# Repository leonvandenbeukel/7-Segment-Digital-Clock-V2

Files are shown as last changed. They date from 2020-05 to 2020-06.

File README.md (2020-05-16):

# 7-Segment-Digital-Clock-V2

This is a new version of a 7 segment digital clocks that uses WS2812B LED's. Instructions how to build can be found in the YouTube video.

## License

<br />This work is licensed under a <a rel="license" href="http://creativecommons.org/licenses/by-nc-sa/4.0/">Creative Commons Attribution-NonCommercial-ShareAlike 4.0 International License</a>.

## Components

| Components | x |
| --- | ----- |
|ESP8266 WeMos Mini D1 | 1x |
|DS3231 RTC | 1x |
|Micro USB Breakout board | 1x |
|Micro USB cable | 1x |
|5V 2.5A power supply | 1x |
|WS2812B LED Strip 60 LED's per meter | 2x |

## 3D Printing

Most files can be printed with 0.3 setting and low infill.

## Schema

Connect D6 from the ESP8266 through a 10 ohm resistor to the data pin of the LED strip. Connect the RTC to gnd, vcc and connect SDA and SCLK to the ESP8266 (check the pin layout of the ESP board you are using). Don't power the LED strip from the ESP board but use a Micro USB breakout board en connect the 5V to the LED strip.

## Arduino code

Upload the .ino file to your ESP board. You also need to upload the html and javascript files with the ESP8266FS tool. Check this link for more info:

http://arduino.esp8266.com/Arduino/versions/2.3.0/doc/filesystem.html#uploading-files-to-file-system

Before uploading the files to your ESP board you have to gzip them with the command:

`gzip -r ./data/`

Afterwards if you want to change something to the html files, just unzip with:

`gunzip -r ./data/`

## YouTube video

<a href="https://youtu.be/tGhew6kTAwc" target="_blank">Click to view: 7 Segment Digital Clock V2</a>

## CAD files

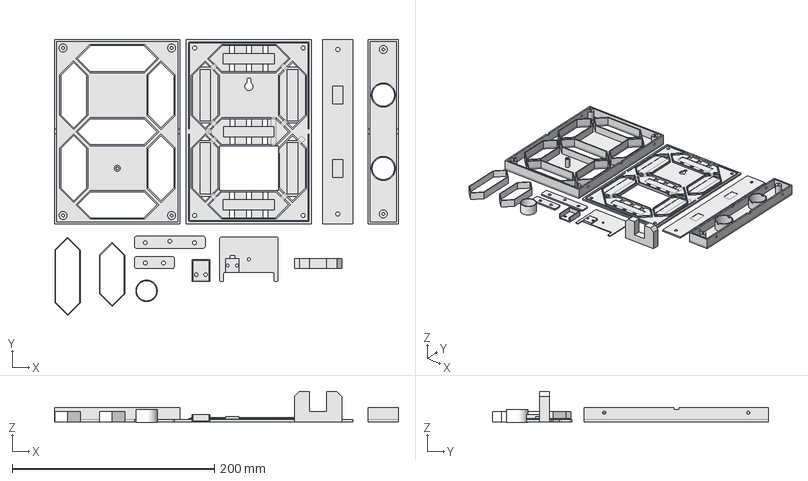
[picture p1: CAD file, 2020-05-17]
Model/3DModel.FCStd
340.0 x 273.0 x 30.8 mm
Bottom
Top
Segment_Vert_Flat
BackLid
MiddleBottom
MiddleTop
Segment_Hor_Flat
Dot
Attach_Large
Attach_Small
USB_Cap
Stand

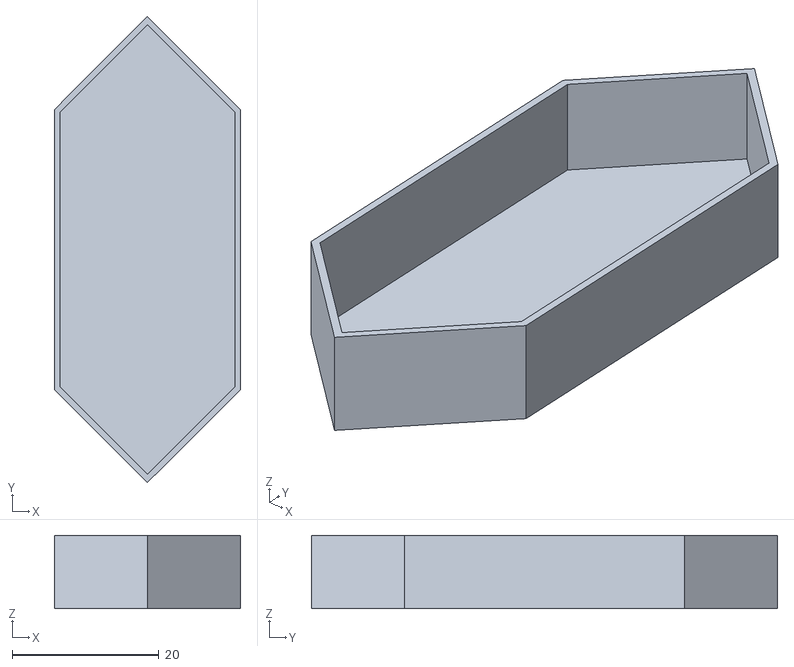
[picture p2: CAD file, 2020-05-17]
STL/Segment_Vert_Flat.stl
25.4 x 63.5 x 10.00

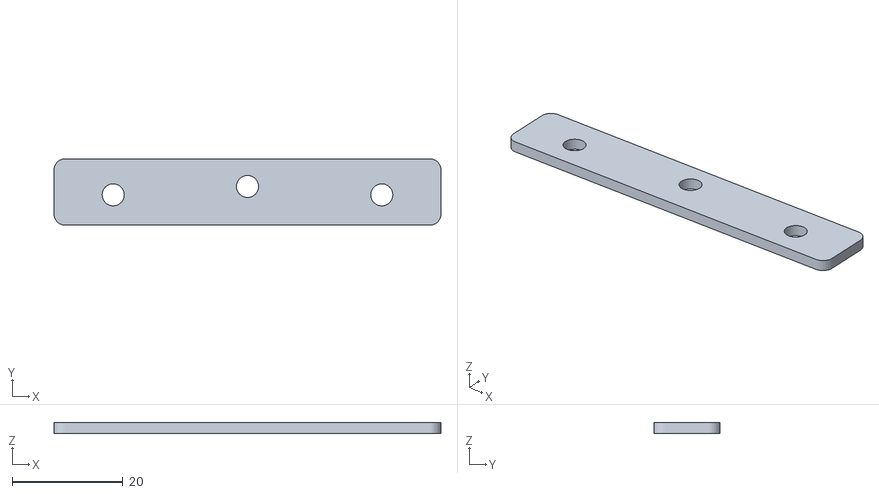
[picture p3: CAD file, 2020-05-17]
STL/Attach_Large.stl
70.0 x 12.0 x 2.00

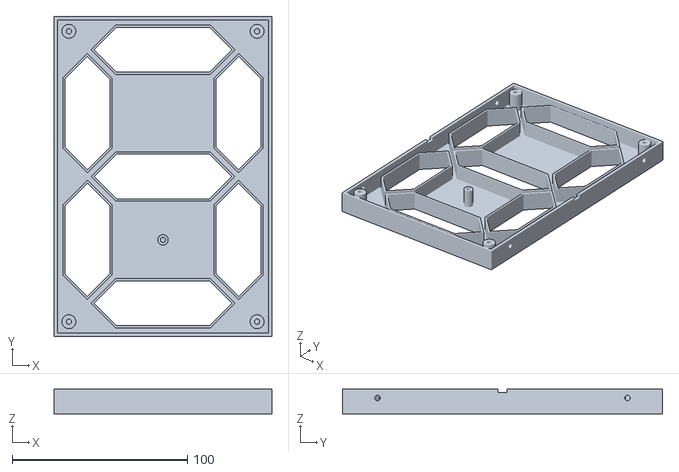
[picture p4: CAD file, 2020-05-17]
STL/Top.stl
124.2 x 182.5 x 14.0

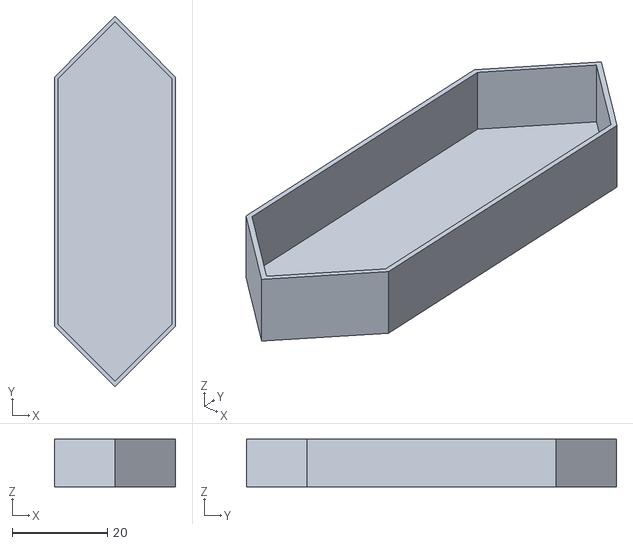
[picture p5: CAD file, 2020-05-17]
STL/Segment_Hor_Flat.stl
25.4 x 77.5 x 10.0

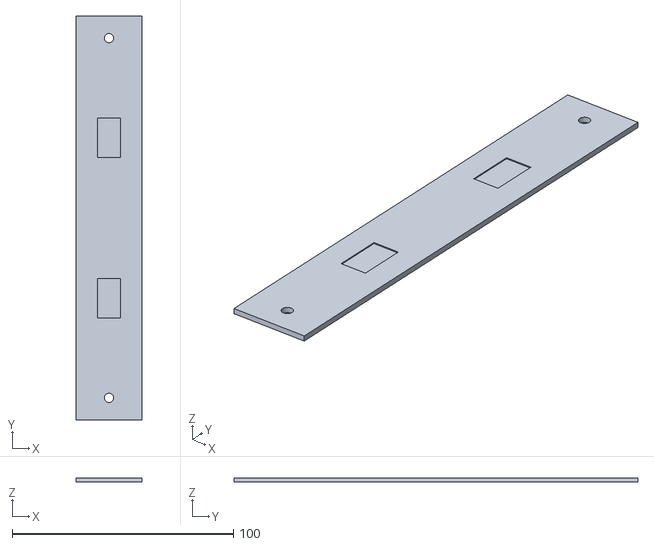
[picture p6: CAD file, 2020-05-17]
STL/MiddleBottom.stl
30.0 x 182.5 x 2.00

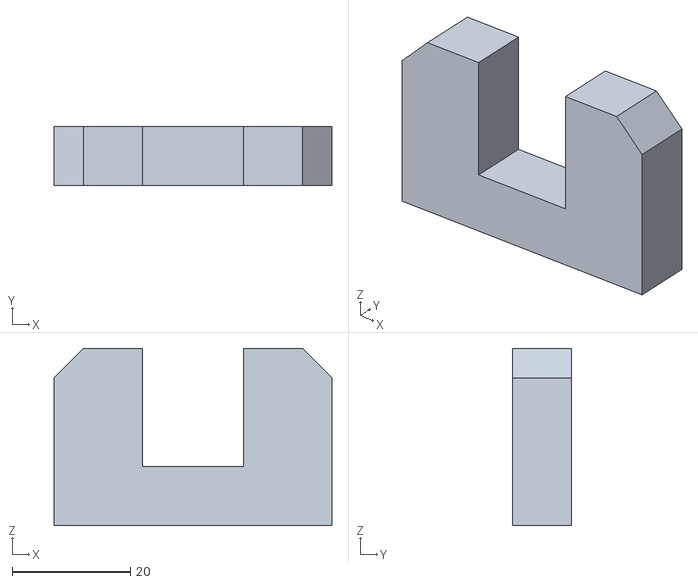
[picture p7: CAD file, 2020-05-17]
STL/Stand.stl
47.0 x 10.0 x 30.0

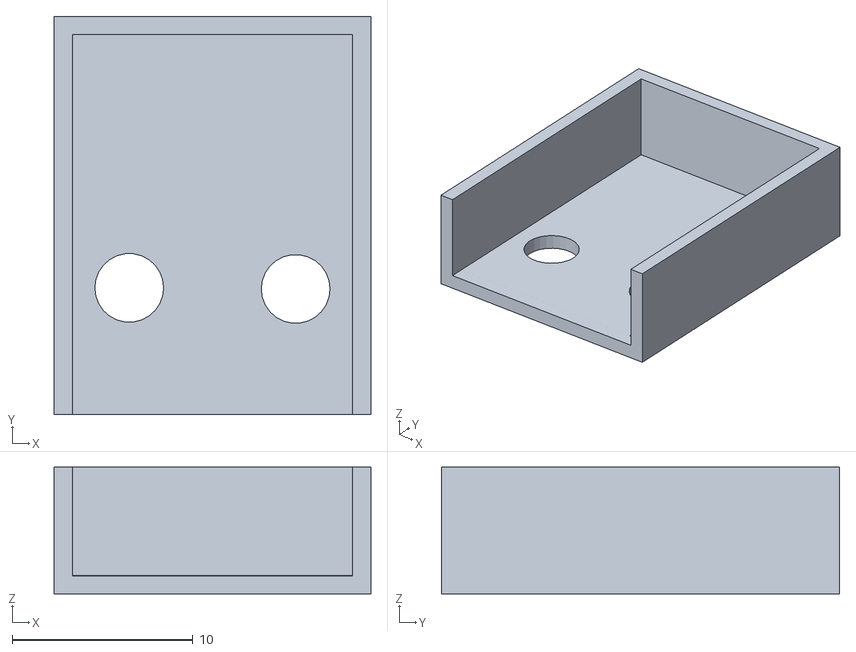
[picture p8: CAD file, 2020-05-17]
STL/USB_Cap.stl
17.5 x 22.0 x 7.00

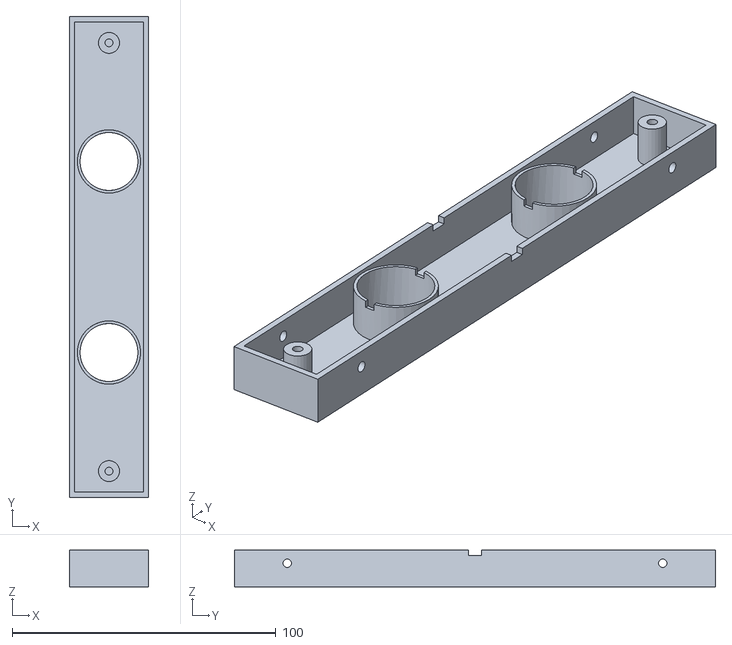
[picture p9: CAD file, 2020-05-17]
STL/MiddleTop.stl
30.0 x 182.5 x 14.0

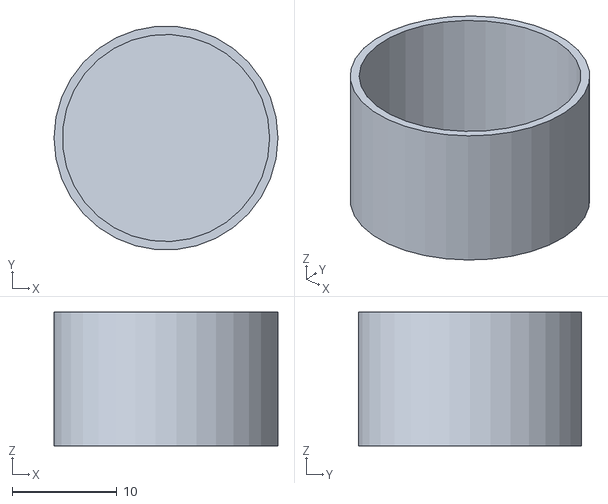
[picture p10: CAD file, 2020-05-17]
STL/Dot.stl
21.4 x 21.3 x 12.8

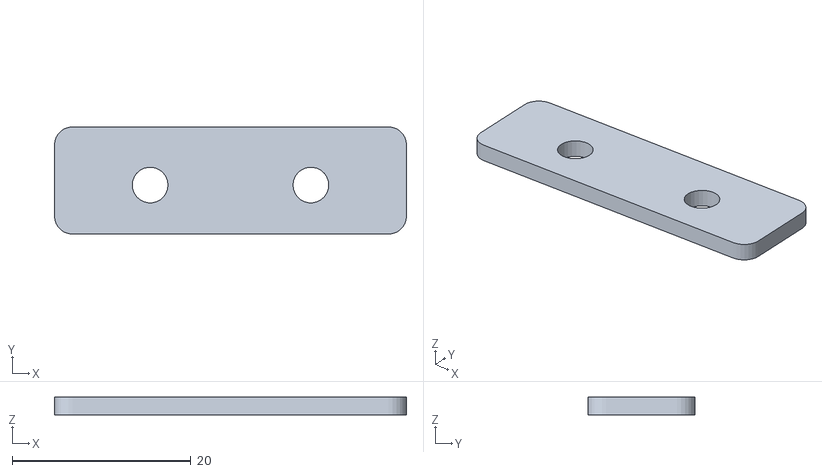
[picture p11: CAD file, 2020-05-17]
STL/Attach_Small.stl
39.4 x 12.0 x 2.00

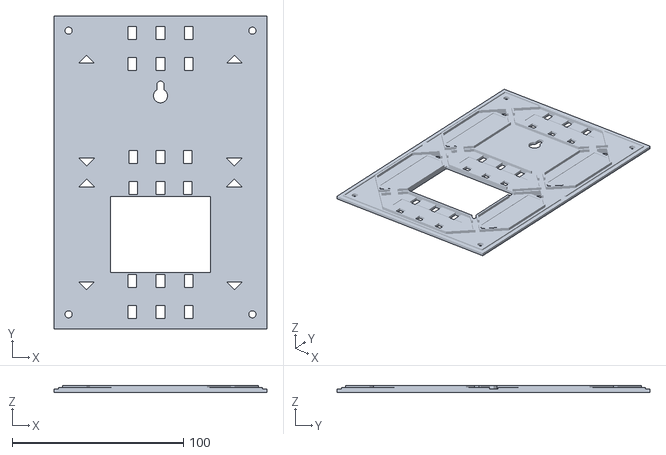
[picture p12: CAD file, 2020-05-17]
STL/Bottom.stl
124.2 x 182.5 x 4.00

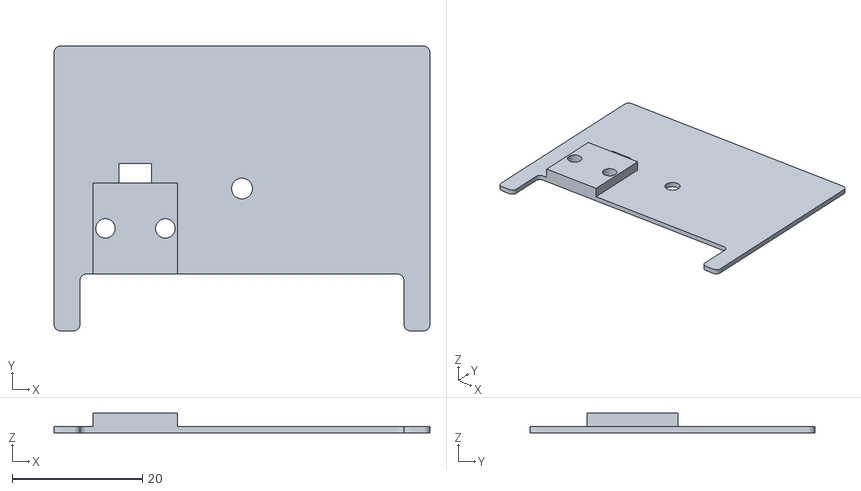
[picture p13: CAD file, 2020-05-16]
STL/Backlid.stl
57.7 x 43.7 x 3.00

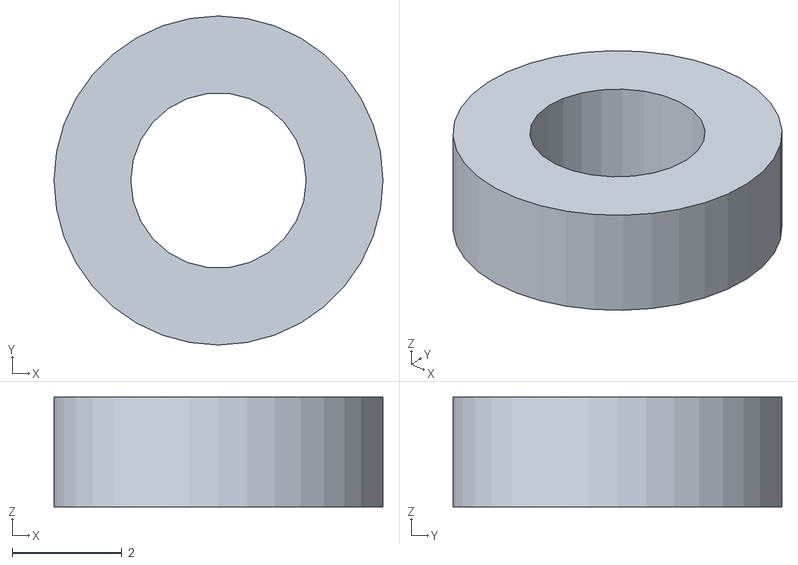
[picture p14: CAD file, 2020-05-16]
STL/Spacer.stl
6.00 x 6.00 x 2.00

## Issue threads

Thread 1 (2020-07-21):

RTC Pin on ESP8266

GreenRisc, 2020-07-21:
Hi everyone,

the RTC module has a few Pins and i don´t know, which Pins i have to connect on which pins on the esp8266.
My second problem is, the clock is blinking red. Why?

best wishes

yusufsulaiman, 2021-02-24:
scl D1
SDA D2

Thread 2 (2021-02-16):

Add 5 LED / Strip - 7 Segment Digital Clock

Eka1911, 2021-02-16:
Dear Leon,

I tried to make it by increasing the number of LEDs / Strips, from 3 LEDs to 5 LEDs.

But when you turn it on, many of the leds don't light up.
The following sketch that I changed.

Please provide solutions and directions, so that it can be perfect.

Thank you.

#include <Wire.h>
#include <RtcDS3231.h>                        // Include RTC library by Makuna: https://github.com/Makuna/Rtc
#include <ESP8266WiFi.h>
#include <ESP8266WebServer.h>
#include <ESP8266HTTPUpdateServer.h>
#include <FastLED.h>
#include <FS.h>                               // Please read the instructions on http://arduino.esp8266.com/Arduino/versions/2.3.0/doc/filesystem.html#uploading-files-to-file-system
#define countof(a) (sizeof(a) / sizeof(a[0]))
#define NUM_LEDS 142                           // Total of 142 LED's    ////5 led per segment X 7 segment X 4 digit + 2 dot titik
#define DATA_PIN D6                           // Change this if you are using another type of ESP board than a WeMos D1 Mini
#define MILLI_AMPS 4000                        // asumsi 800mA jika 1ed per segment maka 5 ledper segment 4.000mA
#define COUNTDOWN_OUTPUT D5                    // COUNTDOWN_OUTPUT D5 to buzzer 3 beeps when the countdown timer is reached

#define WIFIMODE 2                            // 0 = Only Soft Access Point, 1 = Only connect to local WiFi network with UN/PW, 2 = Both

#if defined(WIFIMODE) && (WIFIMODE == 0 || WIFIMODE == 2)
  const char* APssid = "7Segment-5Led";
  const char* APpassword = "1234567890";
#endif

#if defined(WIFIMODE) && (WIFIMODE == 1 || WIFIMODE == 2)
  #include "Credentials.h"                    // Create this file in the same directory as the .ino file and add your credentials (#define SID YOURSSID and on the second line #define PW YOURPASSWORD)
  const char *ssid = SID;
  const char *password = PW;
#endif

RtcDS3231<TwoWire> Rtc(Wire);
ESP8266WebServer server(80);
ESP8266HTTPUpdateServer httpUpdateServer;
CRGB LEDs[NUM_LEDS];

// Settings
unsigned long prevTime = 0;
byte r_val = 255;
byte g_val = 0;
byte b_val = 0;
bool dotsOn = true;
byte brightness = 255;
float temperatureCorrection = -3.0;
byte temperatureSymbol = 12;                  // 12=Celcius, 13=Fahrenheit check 'numbers'
byte clockMode = 0;                           // Clock modes: 0=Clock, 1=Countdown, 2=Temperature, 3=Scoreboard
unsigned long countdownMilliSeconds;
unsigned long endCountDownMillis;
byte hourFormat = 24;                         // Change this to 12 if you want default 12 hours format instead of 24       
CRGB countdownColor = CRGB::Green;
byte scoreboardLeft = 0;
byte scoreboardRight = 0;
CRGB scoreboardColorLeft = CRGB::Green;
CRGB scoreboardColorRight = CRGB::Red;
CRGB alternateColor = CRGB::Black;
long numbers[] = {
  0b00000111111111111111111111111111111,  // [0] 0                  ////5 led per segment
  0b00000111110000000000000000000011111,  // [1] 1                  ////5 led per segment
  0b11111111111111100000111111111100000,  // [2] 2                  ////5 led per segment
  0b11111111111111100000000001111111111,  // [3] 3                  ////5 led per segment
  0b11111111110000011111000000000011111,  // [4] 4                  ////5 led per segment
  0b11111000001111111111000001111111111,  // [5] 5                  ////5 led per segment
  0b11111000001111111111111111111111111,  // [6] 6                  ////5 led per segment
  0b00000111111111100000000000000011111,  // [7] 7                  ////5 led per segment
  0b11111111111111111111111111111111111,  // [8] 8                  ////5 led per segment
  0b11111111111111111111000001111111111,  // [9] 9                  ////5 led per segment
  0b00000000000000000000000000000000000,  // [10] off               ////5 led per segment
  0b11111111111111111111000000000000000,  // [11] degrees symbol    ////5 led per segment
  0b00000000001111111111111111111100000,  // [12] C(elsius)         ////5 led per segment
  0b11111000001111111111111110000000000,  // [13] F(ahrenheit)      ////5 led per segment
};

void setup() {
  pinMode(COUNTDOWN_OUTPUT, OUTPUT);
  Serial.begin(115200);
  delay(200);

  // RTC DS3231 Setup
  Rtc.Begin();
  RtcDateTime compiled = RtcDateTime(__DATE__, __TIME__);

  if (!Rtc.IsDateTimeValid()) {
      if (Rtc.LastError() != 0) {
          // we have a communications error see https://www.arduino.cc/en/Reference/WireEndTransmission for what the number means
          Serial.print("RTC communications error = ");
          Serial.println(Rtc.LastError());
      } else {
          // Common Causes:
          //    1) first time you ran and the device wasn't running yet
          //    2) the battery on the device is low or even missing
          Serial.println("RTC lost confidence in the DateTime!");
          // following line sets the RTC to the date & time this sketch was compiled
          // it will also reset the valid flag internally unless the Rtc device is
          // having an issue
          Rtc.SetDateTime(compiled);
      }
  }

  WiFi.setSleepMode(WIFI_NONE_SLEEP);

  delay(200);
  //Serial.setDebugOutput(true);

  FastLED.addLeds<WS2812B, DATA_PIN, GRB>(LEDs, NUM_LEDS);
  FastLED.setDither(false);
  FastLED.setCorrection(TypicalLEDStrip);
  FastLED.setMaxPowerInVoltsAndMilliamps(5, MILLI_AMPS);
  fill_solid(LEDs, NUM_LEDS, CRGB::Black);
  FastLED.show();

  // WiFi - AP Mode or both
#if defined(WIFIMODE) && (WIFIMODE == 0 || WIFIMODE == 2)
  WiFi.mode(WIFI_AP_STA);
  WiFi.softAP(APssid, APpassword);    // IP is usually 192.168.4.1
  Serial.println();
  Serial.print("SoftAP IP: ");
  Serial.println(WiFi.softAPIP());
#endif

  // WiFi - Local network Mode or both
#if defined(WIFIMODE) && (WIFIMODE == 1 || WIFIMODE == 2)
  byte count = 0;
  WiFi.begin(ssid, password);
  while (WiFi.status() != WL_CONNECTED) {
    // Stop if cannot connect
    if (count >= 60) {
      Serial.println("Could not connect to local WiFi.");
      return;
    }

    delay(500);
    Serial.print(".");
    LEDs[count] = CRGB::Green;
    FastLED.show();
    count++;
  }
  Serial.print("Local IP: ");
  Serial.println(WiFi.localIP());

  IPAddress ip = WiFi.localIP();
  Serial.println(ip[3]);
#endif

  httpUpdateServer.setup(&server);

  // Handlers
  server.on("/color", HTTP_POST, []() {
    r_val = server.arg("r").toInt();
    g_val = server.arg("g").toInt();
    b_val = server.arg("b").toInt();
    server.send(200, "text/json", "{\"result\":\"ok\"}");
  });

  server.on("/setdate", HTTP_POST, []() {
    // Sample input: date = "Dec 06 2009", time = "12:34:56"
    // Jan Feb Mar Apr May Jun Jul Aug Sep Oct Nov Dec
    String datearg = server.arg("date");
    String timearg = server.arg("time");
    Serial.println(datearg);
    Serial.println(timearg);
    char d[12];
    char t[9];
    datearg.toCharArray(d, 12);
    timearg.toCharArray(t, 9);
    RtcDateTime compiled = RtcDateTime(d, t);
    Rtc.SetDateTime(compiled);
    clockMode = 0;
    server.send(200, "text/json", "{\"result\":\"ok\"}");
  });

  server.on("/brightness", HTTP_POST, []() {
    brightness = server.arg("brightness").toInt();
    server.send(200, "text/json", "{\"result\":\"ok\"}");
  });

  server.on("/countdown", HTTP_POST, []() {
    countdownMilliSeconds = server.arg("ms").toInt();
    byte cd_r_val = server.arg("r").toInt();
    byte cd_g_val = server.arg("g").toInt();
    byte cd_b_val = server.arg("b").toInt();
    digitalWrite(COUNTDOWN_OUTPUT, LOW);
    countdownColor = CRGB(cd_r_val, cd_g_val, cd_b_val);
    endCountDownMillis = millis() + countdownMilliSeconds;
    allBlank();
    clockMode = 1;
    server.send(200, "text/json", "{\"result\":\"ok\"}");
  });
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
niall-cooley, 2021-04-08:
Hi @MacGyverr im not 100% sure I would need to try it… You could possibly use a float?

helpquick, 2021-04-08:
@MacGyverr @niall-cooley
You can't use float or double as the numbers array essentially holds a bitmap of which LEDs should be lit or not for each digit.

Why will ``long long`` not work? it should be 64 bits, which is enough to hold the required 49-bit bitmap? (I haven't actually tried more than 3 LEDs per segment).

niall-cooley, 2021-04-08:
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

@helpquick  your completely right I didn’t think on it like that! Just an update with help from your comments above I got 2 per segment working perfectly 😊
![Uploading 0206B1BD-874F-4C83-B346-B5FC2F80FC94.jpeg…]()

MacGyverr, 2021-04-08:
It starts to do weird things above 32 per segment, like never turning off certain lights and turning on less than the number it should, and if I use long long, the 32nd or 33rd light stays out all down the strip and it doesn't work right.
This array method looks promising:
byte digits[12][28] = {{0,0,0,0,1,1,1,1,1,1,1,1,1,1,1,1,1,1,1,1,1,1,1,1,1,1,1,1},   // Digit 0
                       {0,0,0,0,1,1,1,1,0,0,0,0,0,0,0,0,0,0,0,0,0,0,0,0,1,1,1,1},   // Digit 1
                       {1,1,1,1,1,1,1,1,1,1,1,1,0,0,0,0,1,1,1,1,1,1,1,1,0,0,0,0},   // Digit 2
                       {1,1,1,1,1,1,1,1,1,1,1,1,0,0,0,0,0,0,0,0,1,1,1,1,1,1,1,1},   // Digit 3
                       {1,1,1,1,1,1,1,1,0,0,0,0,1,1,1,1,0,0,0,0,0,0,0,0,1,1,1,1},   // Digit 4
                       {1,1,1,1,0,0,0,0,1,1,1,1,1,1,1,1,0,0,0,0,1,1,1,1,1,1,1,1},   // Digit 5
                       {1,1,1,1,0,0,0,0,1,1,1,1,1,1,1,1,1,1,1,1,1,1,1,1,1,1,1,1},   // Digit 6
                       {0,0,0,0,1,1,1,1,1,1,1,1,0,0,0,0,0,0,0,0,0,0,0,0,1,1,1,1},   // Digit 7
                       {1,1,1,1,1,1,1,1,1,1,1,1,1,1,1,1,1,1,1,1,1,1,1,1,1,1,1,1},   // Digit 8
                       {1,1,1,1,1,1,1,1,1,1,1,1,1,1,1,1,0,0,0,0,1,1,1,1,1,1,1,1},   // Digit 9 | 2D Array for numbers on 7 segment
                       {1,1,1,1,1,1,1,1,1,1,1,1,1,1,1,1,0,0,0,0,0,0,0,0,0,0,0,0},   // Digit *0
                       {0,0,0,0,0,0,0,0,1,1,1,1,1,1,1,1,1,1,1,1,1,1,1,1,0,0,0,0}};  // Digit C
and then
      for(int k=0; k<=27;k++){
        // Serial.print(digits[digit][k]);
        if (digits[digit][k]== 1){leds[cursor]=ledColor;}
         else if (digits[digit][k]==0){leds[cursor]=0x000000;};
         cursor ++;
        };
But my complete lack of programming skills and my inability to fix a simple size issue, makes me think I'll never be able to convert Leon's superior web-server based code into using that either. :)

helpquick, 2021-04-08:
Alternative option would be to have the numbers[] array be just 1 bit per segment, then add an extra for loop to expand it to the number of LEDs

```
// bitmap for LEDs
byte numbers[] = {
//  7654321
  0b0111111,  // [0] 0
  0b0100001,  // [1] 1
  0b1110110,  // [2] 2
  0b1110011,  // [3] 3
  0b1101001,  // [4] 4
  0b1011011,  // [5] 5
  0b1011111,  // [6] 6
  0b0110001,  // [7] 7
  0b1111111,  // [8] 8
  0b1111011,  // [9] 9
  0b0000000,  // [10] off
  0b1111000,  // [11] degrees symbol
  0b0011110,  // [12] C(elsius)
  0b1011100,  // [13] F(ahrenheit)
};
```

then:
 in the `displayNumber` function:

```
  for (byte i=0; i<7; i++){                // 7 segments
    for (byte j=0; j<7; j++ {              // 7 LEDs per segment
      yield();
      LEDs[j + i + startindex] = ((numbers[number] & 1 << i) == 1 << i) ? color : alternateColor;
    }
  }
```

This is just an idea, I've not tested it.

MacGyverr, 2021-04-09:
That worked perfectly, I don't know why I didn't think to do that in the first place, it is so simple but so clever and best I can tell, doesn't cause any extra flickering or anything.
Thank you so much, you saved me soooooo much unnecessary work. :)

helpquick, 2021-04-16:
In case anyone is interested, I have uploaded an improved version of the code here: [7-Segment-WiFi-Clock](https://github.com/helpquick/7-Segment-WiFi-Clock)

I am still working on improvements, but as it stands, number of LEDs per segment can be configured, WiFi uses AutoConnect captive portal, so no need for hard-coded SSID / PSK, and time will update from NTP.

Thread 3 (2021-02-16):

Add 5 LED / Strip - 7 Segment Digital Clock

Eka1911, 2021-02-16:
Dear Leon,

I tried to make it by increasing the number of LEDs / Strips, from 3 LEDs to 5 LEDs.

But when you turn it on, many of the leds don't light up.
The following sketch that I changed.

Please provide solutions and directions, so that it can be perfect.

Thank you.

#include <Wire.h>
#include <RtcDS3231.h>                        // Include RTC library by Makuna: https://github.com/Makuna/Rtc
#include <ESP8266WiFi.h>
#include <ESP8266WebServer.h>
#include <ESP8266HTTPUpdateServer.h>
#include <FastLED.h>
#include <FS.h>                               // Please read the instructions on http://arduino.esp8266.com/Arduino/versions/2.3.0/doc/filesystem.html#uploading-files-to-file-system
#define countof(a) (sizeof(a) / sizeof(a[0]))
#define NUM_LEDS 142                           // Total of 142 LED's    ////5 led per segment X 7 segment X 4 digit + 2 dot titik
#define DATA_PIN D6                           // Change this if you are using another type of ESP board than a WeMos D1 Mini
#define MILLI_AMPS 4000                        // asumsi 800mA jika 1ed per segment maka 5 ledper segment 4.000mA
#define COUNTDOWN_OUTPUT D5                    // COUNTDOWN_OUTPUT D5 to buzzer 3 beeps when the countdown timer is reached

#define WIFIMODE 2                            // 0 = Only Soft Access Point, 1 = Only connect to local WiFi network with UN/PW, 2 = Both

#if defined(WIFIMODE) && (WIFIMODE == 0 || WIFIMODE == 2)
  const char* APssid = "7Segment-5Led";
  const char* APpassword = "1234567890";
#endif

#if defined(WIFIMODE) && (WIFIMODE == 1 || WIFIMODE == 2)
  #include "Credentials.h"                    // Create this file in the same directory as the .ino file and add your credentials (#define SID YOURSSID and on the second line #define PW YOURPASSWORD)
  const char *ssid = SID;
  const char *password = PW;
#endif

RtcDS3231<TwoWire> Rtc(Wire);
ESP8266WebServer server(80);
ESP8266HTTPUpdateServer httpUpdateServer;
CRGB LEDs[NUM_LEDS];

// Settings
unsigned long prevTime = 0;
byte r_val = 255;
byte g_val = 0;
byte b_val = 0;
bool dotsOn = true;
byte brightness = 255;
float temperatureCorrection = -3.0;
byte temperatureSymbol = 12;                  // 12=Celcius, 13=Fahrenheit check 'numbers'
byte clockMode = 0;                           // Clock modes: 0=Clock, 1=Countdown, 2=Temperature, 3=Scoreboard
unsigned long countdownMilliSeconds;
unsigned long endCountDownMillis;
byte hourFormat = 24;                         // Change this to 12 if you want default 12 hours format instead of 24       
CRGB countdownColor = CRGB::Green;
byte scoreboardLeft = 0;
byte scoreboardRight = 0;
CRGB scoreboardColorLeft = CRGB::Green;
CRGB scoreboardColorRight = CRGB::Red;
CRGB alternateColor = CRGB::Black;
long numbers[] = {
  0b00000111111111111111111111111111111,  // [0] 0                  ////5 led per segment
  0b00000111110000000000000000000011111,  // [1] 1                  ////5 led per segment
  0b11111111111111100000111111111100000,  // [2] 2                  ////5 led per segment
  0b11111111111111100000000001111111111,  // [3] 3                  ////5 led per segment
  0b11111111110000011111000000000011111,  // [4] 4                  ////5 led per segment
  0b11111000001111111111000001111111111,  // [5] 5                  ////5 led per segment
  0b11111000001111111111111111111111111,  // [6] 6                  ////5 led per segment
  0b00000111111111100000000000000011111,  // [7] 7                  ////5 led per segment
  0b11111111111111111111111111111111111,  // [8] 8                  ////5 led per segment
  0b11111111111111111111000001111111111,  // [9] 9                  ////5 led per segment
  0b00000000000000000000000000000000000,  // [10] off               ////5 led per segment
  0b11111111111111111111000000000000000,  // [11] degrees symbol    ////5 led per segment
  0b00000000001111111111111111111100000,  // [12] C(elsius)         ////5 led per segment
  0b11111000001111111111111110000000000,  // [13] F(ahrenheit)      ////5 led per segment
};

void setup() {
  pinMode(COUNTDOWN_OUTPUT, OUTPUT);
  Serial.begin(115200);
  delay(200);

  // RTC DS3231 Setup
  Rtc.Begin();
  RtcDateTime compiled = RtcDateTime(__DATE__, __TIME__);

  if (!Rtc.IsDateTimeValid()) {
      if (Rtc.LastError() != 0) {
          // we have a communications error see https://www.arduino.cc/en/Reference/WireEndTransmission for what the number means
          Serial.print("RTC communications error = ");
          Serial.println(Rtc.LastError());
      } else {
          // Common Causes:
          //    1) first time you ran and the device wasn't running yet
          //    2) the battery on the device is low or even missing
          Serial.println("RTC lost confidence in the DateTime!");
          // following line sets the RTC to the date & time this sketch was compiled
          // it will also reset the valid flag internally unless the Rtc device is
          // having an issue
          Rtc.SetDateTime(compiled);
      }
  }

  WiFi.setSleepMode(WIFI_NONE_SLEEP);

  delay(200);
  //Serial.setDebugOutput(true);

  FastLED.addLeds<WS2812B, DATA_PIN, GRB>(LEDs, NUM_LEDS);
  FastLED.setDither(false);
  FastLED.setCorrection(TypicalLEDStrip);
  FastLED.setMaxPowerInVoltsAndMilliamps(5, MILLI_AMPS);
  fill_solid(LEDs, NUM_LEDS, CRGB::Black);
  FastLED.show();

  // WiFi - AP Mode or both
#if defined(WIFIMODE) && (WIFIMODE == 0 || WIFIMODE == 2)
  WiFi.mode(WIFI_AP_STA);
  WiFi.softAP(APssid, APpassword);    // IP is usually 192.168.4.1
  Serial.println();
  Serial.print("SoftAP IP: ");
  Serial.println(WiFi.softAPIP());
#endif

  // WiFi - Local network Mode or both
#if defined(WIFIMODE) && (WIFIMODE == 1 || WIFIMODE == 2)
  byte count = 0;
  WiFi.begin(ssid, password);
  while (WiFi.status() != WL_CONNECTED) {
    // Stop if cannot connect
    if (count >= 60) {
      Serial.println("Could not connect to local WiFi.");
      return;
    }

    delay(500);
    Serial.print(".");
    LEDs[count] = CRGB::Green;
    FastLED.show();
    count++;
  }
  Serial.print("Local IP: ");
  Serial.println(WiFi.localIP());

  IPAddress ip = WiFi.localIP();
  Serial.println(ip[3]);
#endif

  httpUpdateServer.setup(&server);

  // Handlers
  server.on("/color", HTTP_POST, []() {
    r_val = server.arg("r").toInt();
    g_val = server.arg("g").toInt();
    b_val = server.arg("b").toInt();
    server.send(200, "text/json", "{\"result\":\"ok\"}");
  });

  server.on("/setdate", HTTP_POST, []() {
    // Sample input: date = "Dec 06 2009", time = "12:34:56"
    // Jan Feb Mar Apr May Jun Jul Aug Sep Oct Nov Dec
    String datearg = server.arg("date");
    String timearg = server.arg("time");
    Serial.println(datearg);
    Serial.println(timearg);
    char d[12];
    char t[9];
    datearg.toCharArray(d, 12);
    timearg.toCharArray(t, 9);
    RtcDateTime compiled = RtcDateTime(d, t);
    Rtc.SetDateTime(compiled);
    clockMode = 0;
    server.send(200, "text/json", "{\"result\":\"ok\"}");
  });

  server.on("/brightness", HTTP_POST, []() {
    brightness = server.arg("brightness").toInt();
    server.send(200, "text/json", "{\"result\":\"ok\"}");
  });

  server.on("/countdown", HTTP_POST, []() {
    countdownMilliSeconds = server.arg("ms").toInt();
    byte cd_r_val = server.arg("r").toInt();
    byte cd_g_val = server.arg("g").toInt();
    byte cd_b_val = server.arg("b").toInt();
    digitalWrite(COUNTDOWN_OUTPUT, LOW);
    countdownColor = CRGB(cd_r_val, cd_g_val, cd_b_val);
    endCountDownMillis = millis() + countdownMilliSeconds;
    allBlank();
    clockMode = 1;
    server.send(200, "text/json", "{\"result\":\"ok\"}");
  });

  server.on("/temperature", HTTP_POST, []() {
    temperatureCorrection = server.arg("correction").toInt();
    temperatureSymbol = server.arg("symbol").toInt();
    clockMode = 2;
    server.send(200, "text/json", "{\"result\":\"ok\"}");
  });

  server.on("/scoreboard", HTTP_POST, []() {
    scoreboardLeft = server.arg("left").toInt();
    scoreboardRight = server.arg("right").toInt();
    scoreboardColorLeft = CRGB(server.arg("rl").toInt(),server.arg("gl").toInt(),server.arg("bl").toInt());
    scoreboardColorRight = CRGB(server.arg("rr").toInt(),server.arg("gr").toInt(),server.arg("br").toInt());
    clockMode = 3;
    server.send(200, "text/json", "{\"result\":\"ok\"}");
  });

  server.on("/hourformat", HTTP_POST, []() {
    hourFormat = server.arg("hourformat").toInt();
    clockMode = 0;
    server.send(200, "text/json", "{\"result\":\"ok\"}");
  });

  server.on("/clock", HTTP_POST, []() {
    clockMode = 0;
    server.send(200, "text/json", "{\"result\":\"ok\"}");
  });

  // Before uploading the files with the "ESP8266 Sketch Data Upload" tool, zip the files with the command "gzip -r ./data/" (on Windows I do this with a Git Bash)
  // *.gz files are automatically unpacked and served from your ESP (so you don't need to create a handler for each file).
  server.serveStatic("/", SPIFFS, "/", "max-age=86400");
  server.begin();

  SPIFFS.begin();
  Serial.println("SPIFFS contents:");
  Dir dir = SPIFFS.openDir("/");
  while (dir.next()) {
    String fileName = dir.fileName();
    size_t fileSize = dir.fileSize();
    Serial.printf("FS File: %s, size: %s\n", fileName.c_str(), String(fileSize).c_str());
  }
  Serial.println();

  digitalWrite(COUNTDOWN_OUTPUT, LOW);
}

void loop(){

  server.handleClient();

  unsigned long currentMillis = millis();
  if (currentMillis - prevTime >= 1000) {
    prevTime = currentMillis;

    if (clockMode == 0) {
      updateClock();
    } else if (clockMode == 1) {
      updateCountdown();
    } else if (clockMode == 2) {
      updateTemperature();
    } else if (clockMode == 3) {
      updateScoreboard();    
    }

    FastLED.setBrightness(brightness);
    FastLED.show();
  }
}

void displayNumber(byte number, byte segment, CRGB color) {
  /*
   *
      __ __ __        __ __ __          __ __ __        12 13 14
    __        __    __        __      __        __    11        15
    __        __    __        __      __        __    10        16
    __        __    __        __ /71  __        __    _9        17
     141 __ __        __ __ __          __ __ __        34 19 18             //////////KETERANGAN BISA DILIHAT DI KONFIGURASI LED 5 PIXEL.JPG           
    __      /107   __        /72 /70  __       /35   _8        _/0
    __        __    __        __      __        __    _7        _1
    __        __    __        __      __        __    _6        _2
      __ __ __       __ __ __           __ __ __       _5 _4 _3

   */

  // segment from left to right: 3, 2, 1, 0
  byte startindex = 0;
  switch (segment) {
    case 0:
      startindex = 0;         //// value start index digit 1 led no 0.
      break;
    case 1:
      startindex = 35;        //// value start index digit 2 led no 35.
      break;
    case 2:
      startindex = 72;        //// value start index digit 3 led no 72.
      break;
    case 3:
      startindex = 107;        //// value start index digit 4 led no 107.
      break;
  }

  for (byte i=0; i<35; i++){   //// value start index digit 2 led no 35.
    yield();
    LEDs[i + startindex] = ((numbers[number] & 1 << i) == 1 << i) ? color : alternateColor;
  }
}

void allBlank() {
  for (int i=0; i<NUM_LEDS; i++) {
    LEDs[i] = CRGB::Black;
  }
  FastLED.show();
}

void updateClock() {
  RtcDateTime now = Rtc.GetDateTime();
  // printDateTime(now);

  int hour = now.Hour();
  int mins = now.Minute();
  int secs = now.Second();

  if (hourFormat == 12 && hour > 12)
    hour = hour - 12;
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
digitongithub, 2023-01-29:
Have 2 questions. Despite the fact that I have made the adjustments and have set the LEDs from 86 to 144 (and byte start index), it remains 3 per segment. I also get an error message with both IP addresses (Not found: /), but also do not get time in the serial monitor. (very sometimes IP address) .  What am I doing wrong?

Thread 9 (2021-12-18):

The first LED is an other color then the rest

Domo5785, 2021-12-18:
Hello,
my problem is that the first LED have an other Color then the rest

JBHTv, 2021-12-30:
I have the same problem

mhmhtssk, 2022-01-11:
Updating FastLed from the libraries section solves the problem. However, this time there is a control delay over wifi.

Protoncek, 2023-12-08:
I know it's old topic, but did you solve "first led problem"? i have this random color first led, too.  I converted my clock to additionally show seconds and  with 3.5.0 library it seems that whole clock runs slower -  two dots doesn't flash at all and seconds update only every two or three seconds... with 3.4.0 runs smoothly, but then first led is a problem...

I'm thinking to insert one led at the front and hide it to eliminate this...

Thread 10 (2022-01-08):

Schematic

Luki3012, 2022-01-08:
Hello,
Can you please put a schematic diagram online. I would like to recreate it.

Best wishes

JBHTv, 2022-01-22:
I used this diagram, but the clock does not show the time, only X0:00. countdown and score board works

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

Luki3012, 2022-01-22:
What is the black component on the left?

JBHTv, 2022-01-22:
a buzzer that works with the countdown

JBHTv, 2022-01-22:
https://es.aliexpress.com/item/32783807336.html
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

Luki3012, 2022-01-25:
Ok. Last question. Where did you get the lib "FastLED.h"?

JBHTv, 2022-01-26:
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

JBHTv, 2022-01-26:
So the connections have been left and the clock already works
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

Luki3012, 2022-01-28:
Thanks

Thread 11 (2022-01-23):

it doesn't work with me

JBHTv, 2022-01-23:
when turning on, the following digits appear X0:00
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

the scoreboard works perfectly
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

the countdown works too
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

temperature is not displayed
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

JBHTv, 2022-01-27:
it worked perfectly after making the connections as follows
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

JBHTv, 2022-03-01:
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

Closed 2022-03-01.

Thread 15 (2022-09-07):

CAN NOT GET THE CODE TO COMPILE Credentials.h

dmp32084, 2022-09-07:
I'm having a really hard time getting the code to compile in the Arduino program.
I am getting lost at the credentials.h   I made a file like your very bad and blunt instructions say to do but it just gets stuck there.
please help I have it all printed and  ready to go just cant get it to work. I have been working at this for weeks now and am getting very frustrated with it.

leonvandenbeukel, 2022-09-07:
The name of the file must start with an uppercase C (Credentials.h). Could that be the problem?

helpquick, 2022-09-07:
Actually, the readme is slightly incorrect. it says to create with UN and PW, but the code says:
```#include "Credentials.h"                    // Create this file in the same directory as the .ino file and add your credentials (#define SID YOURSSID and on the second line #define PW YOURPASSWORD)```

So, your Credentials.h should look like:
```
#define SID "yourssid"
#define PW "yourpassword"
```

Hope that helps.

If not, please post error messages.

dmp32084, 2022-09-08:
well now this is that I get when I get now

Arduino: 1.8.19 (Windows 10), Board: "LOLIN(WEMOS) D1 R2 & mini, 80 MHz, Flash, Disabled (new aborts on oom), Disabled, All SSL ciphers (most compatible), 32KB cache + 32KB IRAM (balanced), Use pgm_read macros for IRAM/PROGMEM, 4MB (FS:2MB OTA:~1019KB), v2 Lower Memory, Disabled, None, Only Sketch, 921600"

C:\Program Files (x86)\Arduino\arduino-builder -dump-prefs -logger=machine -hardware C:\Program Files (x86)\Arduino\hardware -hardware C:\Users\living room\AppData\Local\Arduino15\packages -tools C:\Program Files (x86)\Arduino\tools-builder -tools C:\Program Files (x86)\Arduino\hardware\tools\avr -tools C:\Users\living room\AppData\Local\Arduino15\packages -built-in-libraries C:\Program Files (x86)\Arduino\libraries -libraries C:\Arduino wemos files\libraries -fqbn=esp8266:esp8266:d1_mini:xtal=80,vt=flash,exception=disabled,stacksmash=disabled,ssl=all,mmu=3232,non32xfer=fast,eesz=4M2M,ip=lm2f,dbg=Disabled,lvl=None____,wipe=none,baud=921600 -ide-version=10819 -build-path C:\Users\LIVING~1\AppData\Local\Temp\arduino_build_62009 -warnings=none -build-cache C:\Users\LIVING~1\AppData\Local\Temp\arduino_cache_147851 -prefs=build.warn_data_percentage=75 -prefs=runtime.tools.mklittlefs.path=C:\Users\living room\AppData\Local\Arduino15\packages\esp8266\tools\mklittlefs\3.0.4-gcc10.3-1757bed -prefs=runtime.tools.mklittlefs-3.0.4-gcc10.3-1757bed.path=C:\Users\living room\AppData\Local\Arduino15\packages\esp8266\tools\mklittlefs\3.0.4-gcc10.3-1757bed -prefs=runtime.tools.mkspiffs.path=C:\Users\living room\AppData\Local\Arduino15\packages\esp8266\tools\mkspiffs\3.0.4-gcc10.3-1757bed -prefs=runtime.tools.mkspiffs-3.0.4-gcc10.3-1757bed.path=C:\Users\living room\AppData\Local\Arduino15\packages\esp8266\tools\mkspiffs\3.0.4-gcc10.3-1757bed -prefs=runtime.tools.python3.path=C:\Users\living room\AppData\Local\Arduino15\packages\esp8266\tools\python3\3.7.2-post1 -prefs=runtime.tools.python3-3.7.2-post1.path=C:\Users\living room\AppData\Local\Arduino15\packages\esp8266\tools\python3\3.7.2-post1 -prefs=runtime.tools.xtensa-lx106-elf-gcc.path=C:\Users\living room\AppData\Local\Arduino15\packages\esp8266\tools\xtensa-lx106-elf-gcc\3.0.4-gcc10.3-1757bed -prefs=runtime.tools.xtensa-lx106-elf-gcc-3.0.4-gcc10.3-1757bed.path=C:\Users\living room\AppData\Local\Arduino15\packages\esp8266\tools\xtensa-lx106-elf-gcc\3.0.4-gcc10.3-1757bed -verbose C:\Arduino\7-Segment-Clock\7-Segment-Clock.ino

C:\Program Files (x86)\Arduino\arduino-builder -compile -logger=machine -hardware C:\Program Files (x86)\Arduino\hardware -hardware C:\Users\living room\AppData\Local\Arduino15\packages -tools C:\Program Files (x86)\Arduino\tools-builder -tools C:\Program Files (x86)\Arduino\hardware\tools\avr -tools C:\Users\living room\AppData\Local\Arduino15\packages -built-in-libraries C:\Program Files (x86)\Arduino\libraries -libraries C:\Arduino wemos files\libraries -fqbn=esp8266:esp8266:d1_mini:xtal=80,vt=flash,exception=disabled,stacksmash=disabled,ssl=all,mmu=3232,non32xfer=fast,eesz=4M2M,ip=lm2f,dbg=Disabled,lvl=None____,wipe=none,baud=921600 -ide-version=10819 -build-path C:\Users\LIVING~1\AppData\Local\Temp\arduino_build_62009 -warnings=none -build-cache C:\Users\LIVING~1\AppData\Local\Temp\arduino_cache_147851 -prefs=build.warn_data_percentage=75 -prefs=runtime.tools.mklittlefs.path=C:\Users\living room\AppData\Local\Arduino15\packages\esp8266\tools\mklittlefs\3.0.4-gcc10.3-1757bed -prefs=runtime.tools.mklittlefs-3.0.4-gcc10.3-1757bed.path=C:\Users\living room\AppData\Local\Arduino15\packages\esp8266\tools\mklittlefs\3.0.4-gcc10.3-1757bed -prefs=runtime.tools.mkspiffs.path=C:\Users\living room\AppData\Local\Arduino15\packages\esp8266\tools\mkspiffs\3.0.4-gcc10.3-1757bed -prefs=runtime.tools.mkspiffs-3.0.4-gcc10.3-1757bed.path=C:\Users\living room\AppData\Local\Arduino15\packages\esp8266\tools\mkspiffs\3.0.4-gcc10.3-1757bed -prefs=runtime.tools.python3.path=C:\Users\living room\AppData\Local\Arduino15\packages\esp8266\tools\python3\3.7.2-post1 -prefs=runtime.tools.python3-3.7.2-post1.path=C:\Users\living room\AppData\Local\Arduino15\packages\esp8266\tools\python3\3.7.2-post1 -prefs=runtime.tools.xtensa-lx106-elf-gcc.path=C:\Users\living room\AppData\Local\Arduino15\packages\esp8266\tools\xtensa-lx106-elf-gcc\3.0.4-gcc10.3-1757bed -prefs=runtime.tools.xtensa-lx106-elf-gcc-3.0.4-gcc10.3-1757bed.path=C:\Users\living room\AppData\Local\Arduino15\packages\esp8266\tools\xtensa-lx106-elf-gcc\3.0.4-gcc10.3-1757bed -verbose C:\Arduino\7-Segment-Clock\7-Segment-Clock.ino

Using board 'd1_mini' from platform in folder: C:\Users\living room\AppData\Local\Arduino15\packages\esp8266\hardware\esp8266\3.0.2

Using core 'esp8266' from platform in folder: C:\Users\living room\AppData\Local\Arduino15\packages\esp8266\hardware\esp8266\3.0.2

Detecting libraries used...

"C:\\Users\\living room\\AppData\\Local\\Arduino15\\packages\\esp8266\\tools\\xtensa-lx106-elf-gcc\\3.0.4-gcc10.3-1757bed/bin/xtensa-lx106-elf-g++" -D__ets__ -DICACHE_FLASH -U__STRICT_ANSI__ -D_GNU_SOURCE "-IC:\\Users\\living room\\AppData\\Local\\Arduino15\\packages\\esp8266\\hardware\\esp8266\\3.0.2/tools/sdk/include" "-IC:\\Users\\living room\\AppData\\Local\\Arduino15\\packages\\esp8266\\hardware\\esp8266\\3.0.2/tools/sdk/lwip2/include" "-IC:\\Users\\living room\\AppData\\Local\\Arduino15\\packages\\esp8266\\hardware\\esp8266\\3.0.2/tools/sdk/libc/xtensa-lx106-elf/include" "-IC:\\Users\\LIVING~1\\AppData\\Local\\Temp\\arduino_build_62009/core" -c -w -Werror=return-type -Os -g -free -fipa-pta -mlongcalls -mtext-section-literals -fno-rtti -falign-functions=4 -std=gnu++17 -ffunction-sections -fdata-sections -fno-exceptions -DMMU_IRAM_SIZE=0x8000 -DMMU_ICACHE_SIZE=0x8000 -w -x c++ -E -CC -DNONOSDK22x_190703=1 -DF_CPU=80000000L -DLWIP_OPEN_SRC -DTCP_MSS=536 -DLWIP_FEATURES=1 -DLWIP_IPV6=0 -DARDUINO=10819 -DARDUINO_ESP8266_WEMOS_D1MINI -DARDUINO_ARCH_ESP8266 "-DARDUINO_BOARD=\"ESP8266_WEMOS_D1MINI\"" -DFLASHMODE_DIO -DESP8266 "-IC:\\Users\\living room\\AppData\\Local\\Arduino15\\packages\\esp8266\\hardware\\esp8266\\3.0.2\\cores\\esp8266" "-IC:\\Users\\living room\\AppData\\Local\\Arduino15\\packages\\esp8266\\hardware\\esp8266\\3.0.2\\variants\\d1_mini" "C:\\Users\\LIVING~1\\AppData\\Local\\Temp\\arduino_build_62009\\sketch\\7-Segment-Clock.ino.cpp" -o nul

Alternatives for Wire.h: [Wire@1.0]

ResolveLibrary(Wire.h)

  -> candidates: [Wire@1.0]

"C:\\Users\\living room\\AppData\\Local\\Arduino15\\packages\\esp8266\\tools\\xtensa-lx106-elf-gcc\\3.0.4-gcc10.3-1757bed/bin/xtensa-lx106-elf-g++" -D__ets__ -DICACHE_FLASH -U__STRICT_ANSI__ -D_GNU_SOURCE "-IC:\\Users\\living room\\AppData\\Local\\Arduino15\\packages\\esp8266\\hardware\\esp8266\\3.0.2/tools/sdk/include" "-IC:\\Users\\living room\\AppData\\Local\\Arduino15\\packages\\esp8266\\hardware\\esp8266\\3.0.2/tools/sdk/lwip2/include" "-IC:\\Users\\living room\\AppData\\Local\\Arduino15\\packages\\esp8266\\hardware\\esp8266\\3.0.2/tools/sdk/libc/xtensa-lx106-elf/include" "-IC:\\Users\\LIVING~1\\AppData\\Local\\Temp\\arduino_build_62009/core" -c -w -Werror=return-type -Os -g -free -fipa-pta -mlongcalls -mtext-section-literals -fno-rtti -falign-functions=4 -std=gnu++17 -ffunction-sections -fdata-sections -fno-exceptions -DMMU_IRAM_SIZE=0x8000 -DMMU_ICACHE_SIZE=0x8000 -w -x c++ -E -CC -DNONOSDK22x_190703=1 -DF_CPU=80000000L -DLWIP_OPEN_SRC -DTCP_MSS=536 -DLWIP_FEATURES=1 -DLWIP_IPV6=0 -DARDUINO=10819 -DARDUINO_ESP8266_WEMOS_D1MINI -DARDUINO_ARCH_ESP8266 "-DARDUINO_BOARD=\"ESP8266_WEMOS_D1MINI\"" -DFLASHMODE_DIO -DESP8266 "-IC:\\Users\\living room\\AppData\\Local\\Arduino15\\packages\\esp8266\\hardware\\esp8266\\3.0.2\\cores\\esp8266" "-IC:\\Users\\living room\\AppData\\Local\\Arduino15\\packages\\esp8266\\hardware\\esp8266\\3.0.2\\variants\\d1_mini" "-IC:\\Users\\living room\\AppData\\Local\\Arduino15\\packages\\esp8266\\hardware\\esp8266\\3.0.2\\libraries\\Wire" "C:\\Users\\LIVING~1\\AppData\\Local\\Temp\\arduino_build_62009\\sketch\\7-Segment-Clock.ino.cpp" -o nul

Alternatives for RtcDS3231.h: [Rtc_by_Makuna@2.3.5]

ResolveLibrary(RtcDS3231.h)

  -> candidates: [Rtc_by_Makuna@2.3.5]

"C:\\Users\\living room\\AppData\\Local\\Arduino15\\packages\\esp8266\\tools\\xtensa-lx106-elf-gcc\\3.0.4-gcc10.3-1757bed/bin/xtensa-lx106-elf-g++" -D__ets__ -DICACHE_FLASH -U__STRICT_ANSI__ -D_GNU_SOURCE "-IC:\\Users\\living room\\AppData\\Local\\Arduino15\\packages\\esp8266\\hardware\\esp8266\\3.0.2/tools/sdk/include" "-IC:\\Users\\living room\\AppData\\Local\\Arduino15\\packages\\esp8266\\hardware\\esp8266\\3.0.2/tools/sdk/lwip2/include" "-IC:\\Users\\living room\\AppData\\Local\\Arduino15\\packages\\esp8266\\hardware\\esp8266\\3.0.2/tools/sdk/libc/xtensa-lx106-elf/include" "-IC:\\Users\\LIVING~1\\AppData\\Local\\Temp\\arduino_build_62009/core" -c -w -Werror=return-type -Os -g -free -fipa-pta -mlongcalls -mtext-section-literals -fno-rtti -falign-functions=4 -std=gnu++17 -ffunction-sections -fdata-sections -fno-exceptions -DMMU_IRAM_SIZE=0x8000 -DMMU_ICACHE_SIZE=0x8000 -w -x c++ -E -CC -DNONOSDK22x_190703=1 -DF_CPU=80000000L -DLWIP_OPEN_SRC -DTCP_MSS=536 -DLWIP_FEATURES=1 -DLWIP_IPV6=0 -DARDUINO=10819 -DARDUINO_ESP8266_WEMOS_D1MINI -DARDUINO_ARCH_ESP8266 "-DARDUINO_BOARD=\"ESP8266_WEMOS_D1MINI\"" -DFLASHMODE_DIO -DESP8266 "-IC:\\Users\\living room\\AppData\\Local\\Arduino15\\packages\\esp8266\\hardware\\esp8266\\3.0.2\\cores\\esp8266" "-IC:\\Users\\living room\\AppData\\Local\\Arduino15\\packages\\esp8266\\hardware\\esp8266\\3.0.2\\variants\\d1_mini" "-IC:\\Users\\living room\\AppData\\Local\\Arduino15\\packages\\esp8266\\hardware\\esp8266\\3.0.2\\libraries\\Wire" "-IC:\\Arduino wemos files\\libraries\\Rtc_by_Makuna\\src" "C:\\Users\\LIVING~1\\AppData\\Local\\Temp\\arduino_build_62009\\sketch\\7-Segment-Clock.ino.cpp" -o nul

Alternatives for ESP8266WiFi.h: [ESP8266WiFi@1.0]

ResolveLibrary(ESP8266WiFi.h)

  -> candidates: [ESP8266WiFi@1.0]
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

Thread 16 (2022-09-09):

First led

Muliku82, 2022-09-09:
Hey there.
I rebuilt this awesome project with 1 led instead of 3 led per segment. I changed the .ino therefore.
But I run into the problem that the first led is always on and have another color sen the rest. Anyone a Idee what this would cause?

Fredy12335, 2022-10-26:
Same here. Do you have any updates?

Muliku82, 2022-10-26:
Hey
The problem was the version of the 8266 library, you have to downgrade. The same is for the fasted library, you also need to downgrade

Fredy12335, 2022-10-26:
Thanks!
Work well with ESP8266 v2.7.4 and FastLed lib v3.4.0.

Gogulica, 2023-01-24:
Had the same issue but it's fixed with a different LED strip.

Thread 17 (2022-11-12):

'D5' was not declared in this scope

SachinGGodse, 2022-11-12:
|                         ^~~~~~~

C:\Users\SachinG\Documents\Arduino\libraries\FastLED\src/FastLED.h:315:25: note:   template argument deduction/substitution failed:

wifi_clock:94:57: error: wrong number of template arguments (3, should be 2)

   94 |   FastLED.addLeds<WS2812B, DATA_PIN, RGB>(LEDs, NUM_LEDS);

      |                                                         ^

In file included from E:\wifi_clock\wifi_clock.ino:6:

C:\Users\SachinG\Documents\Arduino\libraries\FastLED\src/FastLED.h:359:25: note: candidate: 'template<template<EOrder RGB_ORDER> class CHIPSET, EOrder RGB_ORDER> static CLEDController& CFastLED::addLeds(CRGB*, int, int)'

  359 |  static CLEDController &addLeds(struct CRGB *data, int nLedsOrOffset, int nLedsIfOffset = 0) {

      |                         ^~~~~~~

C:\Users\SachinG\Documents\Arduino\libraries\FastLED\src/FastLED.h:359:25: note:   template argument deduction/substitution failed:

wifi_clock:94:57: error: wrong number of template arguments (3, should be 2)

   94 |   FastLED.addLeds<WS2812B, DATA_PIN, RGB>(LEDs, NUM_LEDS);

      |                                                         ^

In file included from E:\wifi_clock\wifi_clock.ino:6:

C:\Users\SachinG\Documents\Arduino\libraries\FastLED\src/FastLED.h:365:25: note: candidate: 'template<template<EOrder RGB_ORDER> class CHIPSET> static CLEDController& CFastLED::addLeds(CRGB*, int, int)'

  365 |  static CLEDController &addLeds(struct CRGB *data, int nLedsOrOffset, int nLedsIfOffset = 0) {

      |                         ^~~~~~~

C:\Users\SachinG\Documents\Arduino\libraries\FastLED\src/FastLED.h:365:25: note:   template argument deduction/substitution failed:

wifi_clock:94:57: error: wrong number of template arguments (3, should be 1)

   94 |   FastLED.addLeds<WS2812B, DATA_PIN, RGB>(LEDs, NUM_LEDS);

      |                                                         ^

In file included from E:\wifi_clock\wifi_clock.ino:6:

C:\Users\SachinG\Documents\Arduino\libraries\FastLED\src/FastLED.h:433:25: note: candidate: 'template<EBlockChipsets CHIPSET, int NUM_LANES, EOrder RGB_ORDER> static CLEDController& CFastLED::addLeds(CRGB*, int, int)'

  433 |  static CLEDController &addLeds(struct CRGB *data, int nLedsOrOffset, int nLedsIfOffset = 0) {

      |                         ^~~~~~~

C:\Users\SachinG\Documents\Arduino\libraries\FastLED\src/FastLED.h:433:25: note:   template argument deduction/substitution failed:

wifi_clock:94:57: error: template argument 2 is invalid

   94 |   FastLED.addLeds<WS2812B, DATA_PIN, RGB>(LEDs, NUM_LEDS);

      |                                                         ^

In file included from E:\wifi_clock\wifi_clock.ino:6:

C:\Users\SachinG\Documents\Arduino\libraries\FastLED\src/FastLED.h:474:25: note: candidate: 'template<EBlockChipsets CHIPSET, int NUM_LANES> static CLEDController& CFastLED::addLeds(CRGB*, int, int)'

  474 |  static CLEDController &addLeds(struct CRGB *data, int nLedsOrOffset, int nLedsIfOffset = 0) {

      |                         ^~~~~~~

C:\Users\SachinG\Documents\Arduino\libraries\FastLED\src/FastLED.h:474:25: note:   template argument deduction/substitution failed:

wifi_clock:94:57: error: wrong number of template arguments (3, should be 2)

   94 |   FastLED.addLeds<WS2812B, DATA_PIN, RGB>(LEDs, NUM_LEDS);

      |                                                         ^

E:\wifi_clock\wifi_clock.ino: In lambda function:

wifi_clock:13:26: error: 'D5' is not captured

   13 | #define COUNTDOWN_OUTPUT D5

      |                          ^~

E:\wifi_clock\wifi_clock.ino:166:18: note: in expansion of macro 'COUNTDOWN_OUTPUT'

  166 |     digitalWrite(COUNTDOWN_OUTPUT, LOW);

      |                  ^~~~~~~~~~~~~~~~

E:\wifi_clock\wifi_clock.ino:161:39: note: the lambda has no capture-default

  161 |   server.on("/countdown", HTTP_POST, []() {

      |                                       ^

E:\wifi_clock\wifi_clock.ino:68:11: note: '<typeprefixerror>D5' declared here

   68 |   pinMode(D5, OUTPUT);

      |           ^~

E:\wifi_clock\wifi_clock.ino: In function 'void updateCountdown()':

wifi_clock:13:26: error: 'D5' was not declared in this scope

   13 | #define COUNTDOWN_OUTPUT D5

      |                          ^~

E:\wifi_clock\wifi_clock.ino:353:18: note: in expansion of macro 'COUNTDOWN_OUTPUT'

  353 |     digitalWrite(COUNTDOWN_OUTPUT, HIGH);

      |                  ^~~~~~~~~~~~~~~~

Using library Wire at version 1.0 in folder: C:\Users\SachinG\Documents\ArduinoData\packages\esp8266\hardware\esp8266\3.0.2\libraries\Wire

Using library Rtc-master at version 2.3.5 in folder: C:\Users\SachinG\Documents\Arduino\libraries\Rtc-master

Using library ESP8266WiFi at version 1.0 in folder: C:\Users\SachinG\Documents\Arduino\libraries\ESP8266WiFi

Using library ESP8266WebServer at version 1.0 in folder: C:\Users\SachinG\Documents\ArduinoData\packages\esp8266\hardware\esp8266\3.0.2\libraries\ESP8266WebServer

Using library ESP8266HTTPUpdateServer at version 1.0 in folder: C:\Users\SachinG\Documents\ArduinoData\packages\esp8266\hardware\esp8266\3.0.2\libraries\ESP8266HTTPUpdateServer

Using library FastLED at version 3.5.0 in folder: C:\Users\SachinG\Documents\Arduino\libraries\FastLED

exit status 1

'D5' was not declared in this scope

digitongithub, 2025-01-25:
I built the clock in 2023 and saved the scripty including the corresponding libraries. I now want to make the same clock but also get the DE6 message while everything on the old clock works with this script. What is the solution to this???

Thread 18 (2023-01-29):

Update colors and serial monitor.

digitongithub, 2023-01-29:
In the meantime, we have managed to go from 3 to 5 LEDs, but still do not get a vvindinding with both IP addresses (not found), which very occasionally appears in the serial monitor. But also don't get to see time in the monitor. What am I doing wrong?

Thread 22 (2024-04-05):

Memorize Settings and Wireless Network

rlcardoo, 2024-04-05:
1- It would be very interesting if you could memorize the color settings of the clock, scoreboard and countdown.
2- It would be nice to be able to add the wireless network and password through the web interface, instead of needing to modify the credential.h file and having to compile it every time we need to connect the watch to a different router.
3- When the countdown reaches 0000, the beep sounds non-stop, until you start the countdown again or switch to the Clock.  (I believe it would be solved by just adding a delay and turning off the beep).

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

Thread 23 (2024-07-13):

Cannot change the color in the displayNumber subroutine

billbrach, 2024-07-13:
I have taken your "7-Segment-Clock.ino" sketch and gutted out everything not necessary to display a number on a 5 X 5 LED matrix.  I built 25 bit long numbers, to match the layout of the 5 X 5 LED matrix I bought off of Aliexpress.  The problem is I cannot change the color in the displayNumber() routine.  In the middle of loop(), try changing the CRGB colr line to something w/o Red.  You don't necessarily need a 5 X 5 matrix to test this, any WS2812B strip should work, it just won't display the numbers correctly.

I *think* the problem is in this line, which I don't fully understand:
 LEDs[i + startindex] = ((numbers[number] & 1 << i) == 1 << i) ? color : alternateColor;

Hopefully it is just a stupid mistake on my part !!
THANKS !!

Here is my code:

// ***** CODE START *****
// Demo code for a 5 X 5 WS2812B matrix, purchased from Aliexpress

// Based on the code here: https://github.com/leonvandenbeukel/7-Segment-Digital-Clock-V2/tree/master/7-Segment-Clock
//  but with all non-essential code removed so as to have demo code that only displays the digits 0 thru 9 on a 5x5 matrix

// 5X5 LED matrix from Aliexpress
/* "as the ox plows" coded rows and columns
 *  1  10  11  20  21
 *  2   9  12  19  22
 *  3   8  13  18  23
 *  4   7  14  17  24
 *  5   6  15  16  25
 */

#include <Wire.h>
#include <FastLED.h>
#define NUM_LEDS 25 // 86 // Total of 86 LED's
#define DATA_PIN D6 // Change this if you are using another type of ESP board than a WeMos D1 Mini
#define MILLI_AMPS 1000 //2400

CRGB LEDs[NUM_LEDS];

#define NUM_CLRS 5
uint32_t color[] = {CRGB::Red, CRGB::Green, CRGB::Blue, CRGB::Orange, CRGB::White};

// Settings
byte brightness = 1; // 0 to 255
CRGB alternateColor = CRGB::Black;

/* For this sketch, the segments are ordered as so.  3 WS2812 LED's per segment in SEQUENTIAL ORDER - wjb
 *    5
 *  4   6
 *  3 7 1
 *    2
 */

// Each of these long's are 21 bits long.  3 LED's per segment times 7 segments = 21
//  They also are written backwards, meaning the 1st segment is the last 3 bits in the long.
//    Looking at the ZERO will confirm this, with seg 7, the center segment, being all zeros
//long numbers[] = {
//  0b000111111111111111111,  // [0] 0
//  0b000111000000000000111,  // [1] 1
//  0b111111111000111111000,  // [2] 2
//  0b111111111000000111111,  // [3] 3
//  0b111111000111000000111,  // [4] 4
//  0b111000111111000111111,  // [5] 5
//  0b111000111111111111111,  // [6] 6
//  0b000111111000000000111,  // [7] 7
//  0b111111111111111111111,  // [8] 8
//  0b111111111111000111111,  // [9] 9
//  0b000000000000000000000,  // [10] off
//  0b111111111111000000000,  // [11] degrees symbol
//  0b000000111111111111000,  // [12] C(elsius)
//  0b111000111111111000000,  // [13] F(ahrenheit)
//};

// I built this array for the numbers 0 to 9, using 25 bit longs, for the 5X5 matrix arrays I bought off Aliexpress - wjb
//  2222221111111111
//  5432109876543210987654321
long numbers[] = {
  0b0000011111100011000111111,  // [0] 0
  0b0000000001111111000100000,  // [1] 1
  0b0000011101101011010111101,  // [2] 2
  0b0000011111101011010110101,  // [3] 3
  0b0000011111001000010000111,  // [4] 4
  0b0000010111101011010110111,  // [5] 5
  0b0000000111101001010111111,  // [6] 6
  0b0000011111000011000000011,  // [7] 7
  0b0000011111101011010111111,  // [0] 8
  0b0000011111001011010000111   // [9] 9
};

int td = 1000; // time delay

void setup() {
  Serial.begin(115200);
  Serial.println(); Serial.println();
  Serial.println(__FILE__); // show sketch name in the Serial Monitor.

  FastLED.addLeds<WS2812B, DATA_PIN, GRB>(LEDs, NUM_LEDS);  // GRB order on the LED's is typical for WS2812B LED's
  FastLED.setDither(false);
  FastLED.setCorrection(TypicalLEDStrip);
  FastLED.setMaxPowerInVoltsAndMilliamps(5, MILLI_AMPS);
  fill_solid(LEDs, NUM_LEDS, CRGB::Black); // turn off all LED's
  FastLED.show();
}

void loop() {

  // loop thru all the numbers defined in the array
  for (int i = 0; i <= 9; i++) {

    // generate a random color from those in the array
    byte clr = random(0,NUM_CLRS);
    Serial.print("Random color index: ");  Serial.print(clr); Serial.print(", color number: ");  Serial.println(color[clr]);

    // generate a random number between 0 and 9, to display
    //byte num = random(0,4);
    //displayNumber(num, 0, color[clr]);
    //displayNumber(num, 0, CRGB::Red);
    //Serial.print("Random number to display: "); Serial.println(num);

    CRGB colr = CRGB(255, 255, 255); // <<<<<<<<<<<<< CHANGE COLOR HERE TO SOMETHING W/O RED

    displayNumber(i, 0, colr);
    FastLED.setBrightness(brightness);
    FastLED.show();
    delay(td);
    fill_solid(LEDs, NUM_LEDS, CRGB::Black); // turn off all LED's
    FastLED.show();
  }
}

void displayNumber(byte number, byte segment, CRGB color) {
  /*
   *
      __ __ __        __ __ __          __ __ __        12 13 14
    __        __    __        __      __        __    11        15
    __        __    __        __      __        __    10        16
    __        __    __        __  42  __        __    _9        17
      __ __ __        __ __ __          __ __ __        20 19 18
    __        65    __        44  43  __        21    _8        _0
    __        __    __        __      __        __    _7        _1
    __        __    __        __      __        __    _6        _2
      __ __ __       __ __ __           __ __ __       _5 _4 _3

   */

  // FIX NEEDED HERE  - to correct for the actual # of LED's per segment, as opposed to just 21 - wjb
  // segment from left to right: 3, 2, 1, 0
  byte startindex = 0;
  switch (segment) {
    case 0:
      startindex = 0;
      break;
    case 1:
      startindex = 21;
      break;
    case 2:
      startindex = 44;
      break;
    case 3:
      startindex = 65;
      break;
  }

  //for (byte i=0; i<21; i++){
  for (byte i=0; i<NUM_LEDS; i++) {

    yield();
    LEDs[i + startindex] = ((numbers[number] & 1 << i) == 1 << i) ? color : alternateColor;
  }
}
// ***** CODE END *****

billbrach, 2024-07-13:
FOUND THE PROBLEM !!
Something in these 3 lines screws things up.  I commented them out and it works correctly.

FastLED.setDither(false);
FastLED.setCorrection(TypicalLEDStrip);
FastLED.setMaxPowerInVoltsAndMilliamps(5, MILLI_AMPS);

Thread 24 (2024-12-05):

Web app not serving correctly

chainmaker101, 2024-12-05:
Hi,

I know it is 2024 andI am looking at an old project but i really need some help. Please note I consider myself a noob but will always try and figure stuff out myself if i can. I am but a keen but simple maker not a coding genius.

When I try and connect to the web app it will only show anything in Firefox (opera, edge & Chrome all fail to open even the index page)

What does open seems to be missing the formatting and none of the functions work

if i open the HTML index file locally on any of the above mentioned browsers it all seems to display/respond correctly.

what I get served:
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

What i see opened locally:

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

It took me a while to figure out how to Gzip the data files (I have tried individually with 7zip and batch with Git Bash as suggested)

I have tried a number of ESP8266 boards (D! mini, D1 mini pro, dev board with oled built in) and all behave the same way
i have installed Arduino ide 1.8.19 and got ESP8266FS-0.5.0 working
All Libs and boards seem up to date, as do 3rd party things like LittleFS and ESP8266FS
I have also installed Arduino 2.3.4 and have LitteFS working as from what i cab see ESP8266DS is not supported on 2.x Arduino IDE)

I have erased the flash uploaded via each IDE version, tried 7zipped files git bashed files in just about every permutation i can think

LED's connected or not, RTC or not it makes no difference.

Serial monitor seems to show soft AP, Local IP and the gzipped files flashed in memory

As the html seems to work fine locally i am at a loss.

If anyone can help it would be greatly appreciated, Just let me know what information is required.

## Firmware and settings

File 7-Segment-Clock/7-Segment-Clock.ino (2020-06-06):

#include <Wire.h>
#include <RtcDS3231.h>                        // Include RTC library by Makuna: https://github.com/Makuna/Rtc
#include <ESP8266WiFi.h>
#include <ESP8266WebServer.h>
#include <ESP8266HTTPUpdateServer.h>
#include <FastLED.h>
#include <FS.h>                               // Please read the instructions on http://arduino.esp8266.com/Arduino/versions/2.3.0/doc/filesystem.html#uploading-files-to-file-system
#define countof(a) (sizeof(a) / sizeof(a[0]))
#define NUM_LEDS 86                           // Total of 86 LED's     
#define DATA_PIN D6                           // Change this if you are using another type of ESP board than a WeMos D1 Mini
#define MILLI_AMPS 2400 
#define COUNTDOWN_OUTPUT D5

#define WIFIMODE 2                            // 0 = Only Soft Access Point, 1 = Only connect to local WiFi network with UN/PW, 2 = Both

#if defined(WIFIMODE) && (WIFIMODE == 0 || WIFIMODE == 2)
  const char* APssid = "CLOCK_AP";        
  const char* APpassword = "1234567890";  
#endif
  
#if defined(WIFIMODE) && (WIFIMODE == 1 || WIFIMODE == 2)
  #include "Credentials.h"                    // Create this file in the same directory as the .ino file and add your credentials (#define SID YOURSSID and on the second line #define PW YOURPASSWORD)
  const char *ssid = SID;
  const char *password = PW;
#endif

RtcDS3231<TwoWire> Rtc(Wire);
ESP8266WebServer server(80);
ESP8266HTTPUpdateServer httpUpdateServer;
CRGB LEDs[NUM_LEDS];

// Settings
unsigned long prevTime = 0;
byte r_val = 255;
byte g_val = 0;
byte b_val = 0;
bool dotsOn = true;
byte brightness = 255;
float temperatureCorrection = -3.0;
byte temperatureSymbol = 12;                  // 12=Celcius, 13=Fahrenheit check 'numbers'
byte clockMode = 0;                           // Clock modes: 0=Clock, 1=Countdown, 2=Temperature, 3=Scoreboard
unsigned long countdownMilliSeconds;
unsigned long endCountDownMillis;
byte hourFormat = 24;                         // Change this to 12 if you want default 12 hours format instead of 24               
CRGB countdownColor = CRGB::Green;
byte scoreboardLeft = 0;
byte scoreboardRight = 0;
CRGB scoreboardColorLeft = CRGB::Green;
CRGB scoreboardColorRight = CRGB::Red;
CRGB alternateColor = CRGB::Black; 
long numbers[] = {
  0b000111111111111111111,  // [0] 0
  0b000111000000000000111,  // [1] 1
  0b111111111000111111000,  // [2] 2
  0b111111111000000111111,  // [3] 3
  0b111111000111000000111,  // [4] 4
  0b111000111111000111111,  // [5] 5
  0b111000111111111111111,  // [6] 6
  0b000111111000000000111,  // [7] 7
  0b111111111111111111111,  // [8] 8
  0b111111111111000111111,  // [9] 9
  0b000000000000000000000,  // [10] off
  0b111111111111000000000,  // [11] degrees symbol
  0b000000111111111111000,  // [12] C(elsius)
  0b111000111111111000000,  // [13] F(ahrenheit)
};

void setup() {
  pinMode(COUNTDOWN_OUTPUT, OUTPUT);
  Serial.begin(115200); 
  delay(200);

  // RTC DS3231 Setup
  Rtc.Begin();    
  RtcDateTime compiled = RtcDateTime(__DATE__, __TIME__);

  if (!Rtc.IsDateTimeValid()) {
      if (Rtc.LastError() != 0) {
          // we have a communications error see https://www.arduino.cc/en/Reference/WireEndTransmission for what the number means
          Serial.print("RTC communications error = ");
          Serial.println(Rtc.LastError());
      } else {
          // Common Causes:
          //    1) first time you ran and the device wasn't running yet
          //    2) the battery on the device is low or even missing
          Serial.println("RTC lost confidence in the DateTime!");
          // following line sets the RTC to the date & time this sketch was compiled
          // it will also reset the valid flag internally unless the Rtc device is
          // having an issue
          Rtc.SetDateTime(compiled);
      }
  }

  WiFi.setSleepMode(WIFI_NONE_SLEEP);  

  delay(200);
  //Serial.setDebugOutput(true);

  FastLED.addLeds<WS2812B, DATA_PIN, GRB>(LEDs, NUM_LEDS);  
  FastLED.setDither(false);
  FastLED.setCorrection(TypicalLEDStrip);
  FastLED.setMaxPowerInVoltsAndMilliamps(5, MILLI_AMPS);
  fill_solid(LEDs, NUM_LEDS, CRGB::Black);
  FastLED.show();

  // WiFi - AP Mode or both
#if defined(WIFIMODE) && (WIFIMODE == 0 || WIFIMODE == 2) 
  WiFi.mode(WIFI_AP_STA);
  WiFi.softAP(APssid, APpassword);    // IP is usually 192.168.4.1
  Serial.println();
  Serial.print("SoftAP IP: ");
  Serial.println(WiFi.softAPIP());
#endif

  // WiFi - Local network Mode or both
#if defined(WIFIMODE) && (WIFIMODE == 1 || WIFIMODE == 2) 
  byte count = 0;
  WiFi.begin(ssid, password);
  while (WiFi.status() != WL_CONNECTED) {
    // Stop if cannot connect
    if (count >= 60) {
      Serial.println("Could not connect to local WiFi.");      
      return;
    }
       
    delay(500);
    Serial.print(".");
    LEDs[count] = CRGB::Green;
    FastLED.show();
    count++;
  }
  Serial.print("Local IP: ");
  Serial.println(WiFi.localIP());

  IPAddress ip = WiFi.localIP();
  Serial.println(ip[3]);
#endif   

  httpUpdateServer.setup(&server);

  // Handlers
  server.on("/color", HTTP_POST, []() {    
    r_val = server.arg("r").toInt();
    g_val = server.arg("g").toInt();
    b_val = server.arg("b").toInt();
    server.send(200, "text/json", "{\"result\":\"ok\"}");
  });

  server.on("/setdate", HTTP_POST, []() { 
    // Sample input: date = "Dec 06 2009", time = "12:34:56"
    // Jan Feb Mar Apr May Jun Jul Aug Sep Oct Nov Dec
    String datearg = server.arg("date");
    String timearg = server.arg("time");
    Serial.println(datearg);
    Serial.println(timearg);    
    char d[12];
    char t[9];
    datearg.toCharArray(d, 12);
    timearg.toCharArray(t, 9);
    RtcDateTime compiled = RtcDateTime(d, t);
    Rtc.SetDateTime(compiled);   
    clockMode = 0;     
    server.send(200, "text/json", "{\"result\":\"ok\"}");
  });

  server.on("/brightness", HTTP_POST, []() {    
    brightness = server.arg("brightness").toInt();    
    server.send(200, "text/json", "{\"result\":\"ok\"}");
  });
  
  server.on("/countdown", HTTP_POST, []() {    
    countdownMilliSeconds = server.arg("ms").toInt();     
    byte cd_r_val = server.arg("r").toInt();
    byte cd_g_val = server.arg("g").toInt();
    byte cd_b_val = server.arg("b").toInt();
    digitalWrite(COUNTDOWN_OUTPUT, LOW);
    countdownColor = CRGB(cd_r_val, cd_g_val, cd_b_val); 
    endCountDownMillis = millis() + countdownMilliSeconds;
    allBlank(); 
    clockMode = 1;     
    server.send(200, "text/json", "{\"result\":\"ok\"}");
  });

  server.on("/temperature", HTTP_POST, []() {   
    temperatureCorrection = server.arg("correction").toInt();
    temperatureSymbol = server.arg("symbol").toInt();
    clockMode = 2;     
    server.send(200, "text/json", "{\"result\":\"ok\"}");
  });  

  server.on("/scoreboard", HTTP_POST, []() {   
    scoreboardLeft = server.arg("left").toInt();
    scoreboardRight = server.arg("right").toInt();
    scoreboardColorLeft = CRGB(server.arg("rl").toInt(),server.arg("gl").toInt(),server.arg("bl").toInt());
    scoreboardColorRight = CRGB(server.arg("rr").toInt(),server.arg("gr").toInt(),server.arg("br").toInt());
    clockMode = 3;     
    server.send(200, "text/json", "{\"result\":\"ok\"}");
  });  

  server.on("/hourformat", HTTP_POST, []() {   
    hourFormat = server.arg("hourformat").toInt();
    clockMode = 0;     
    server.send(200, "text/json", "{\"result\":\"ok\"}");
  }); 

  server.on("/clock", HTTP_POST, []() {       
    clockMode = 0;     
    server.send(200, "text/json", "{\"result\":\"ok\"}");
  });  
  
  // Before uploading the files with the "ESP8266 Sketch Data Upload" tool, zip the files with the command "gzip -r ./data/" (on Windows I do this with a Git Bash)
  // *.gz files are automatically unpacked and served from your ESP (so you don't need to create a handler for each file).
  server.serveStatic("/", SPIFFS, "/", "max-age=86400");
  server.begin();     

  SPIFFS.begin();
  Serial.println("SPIFFS contents:");
  Dir dir = SPIFFS.openDir("/");
  while (dir.next()) {
    String fileName = dir.fileName();
    size_t fileSize = dir.fileSize();
    Serial.printf("FS File: %s, size: %s\n", fileName.c_str(), String(fileSize).c_str());
  }
  Serial.println(); 
  
  digitalWrite(COUNTDOWN_OUTPUT, LOW);
}

void loop(){

  server.handleClient(); 
  
  unsigned long currentMillis = millis();  
  if (currentMillis - prevTime >= 1000) {
    prevTime = currentMillis;

    if (clockMode == 0) {
      updateClock();
    } else if (clockMode == 1) {
      updateCountdown();
    } else if (clockMode == 2) {
      updateTemperature();      
    } else if (clockMode == 3) {
      updateScoreboard();            
    }

    FastLED.setBrightness(brightness);
    FastLED.show();
  }   
}

void displayNumber(byte number, byte segment, CRGB color) {
  /*
   * 
      __ __ __        __ __ __          __ __ __        12 13 14  
    __        __    __        __      __        __    11        15
    __        __    __        __      __        __    10        16
    __        __    __        __  42  __        __    _9        17
      __ __ __        __ __ __          __ __ __        20 19 18  
    __        65    __        44  43  __        21    _8        _0
    __        __    __        __      __        __    _7        _1
    __        __    __        __      __        __    _6        _2
      __ __ __       __ __ __           __ __ __       _5 _4 _3   

   */
 
  // segment from left to right: 3, 2, 1, 0
  byte startindex = 0;
  switch (segment) {
    case 0:
      startindex = 0;
      break;
    case 1:
      startindex = 21;
      break;
    case 2:
      startindex = 44;
      break;
    case 3:
      startindex = 65;
      break;    
  }

  for (byte i=0; i<21; i++){
    yield();
    LEDs[i + startindex] = ((numbers[number] & 1 << i) == 1 << i) ? color : alternateColor;
  } 
}

void allBlank() {
  for (int i=0; i<NUM_LEDS; i++) {
    LEDs[i] = CRGB::Black;
  }
  FastLED.show();
}

void updateClock() {  
  RtcDateTime now = Rtc.GetDateTime();
  // printDateTime(now);    

  int hour = now.Hour();
  int mins = now.Minute();
  int secs = now.Second();

  if (hourFormat == 12 && hour > 12)
    hour = hour - 12;
  
  byte h1 = hour / 10;
  byte h2 = hour % 10;
  byte m1 = mins / 10;
  byte m2 = mins % 10;  
  byte s1 = secs / 10;
  byte s2 = secs % 10;
  
  CRGB color = CRGB(r_val, g_val, b_val);

  if (h1 > 0)
    displayNumber(h1,3,color);
  else 
    displayNumber(10,3,color);  // Blank
    
  displayNumber(h2,2,color);
  displayNumber(m1,1,color);
  displayNumber(m2,0,color); 

  displayDots(color);  
}

void updateCountdown() {

  if (countdownMilliSeconds == 0 && endCountDownMillis == 0) 
    return;
    
  unsigned long restMillis = endCountDownMillis - millis();
  unsigned long hours   = ((restMillis / 1000) / 60) / 60;
  unsigned long minutes = (restMillis / 1000) / 60;
  unsigned long seconds = restMillis / 1000;
  int remSeconds = seconds - (minutes * 60);
  int remMinutes = minutes - (hours * 60); 
  
  Serial.print(restMillis);
  Serial.print(" ");
  Serial.print(hours);
  Serial.print(" ");
  Serial.print(minutes);
  Serial.print(" ");
  Serial.print(seconds);
  Serial.print(" | ");
  Serial.print(remMinutes);
  Serial.print(" ");
  Serial.println(remSeconds);

  byte h1 = hours / 10;
  byte h2 = hours % 10;
  byte m1 = remMinutes / 10;
  byte m2 = remMinutes % 10;  
  byte s1 = remSeconds / 10;
  byte s2 = remSeconds % 10;

  CRGB color = countdownColor;
  if (restMillis <= 60000) {
    color = CRGB::Red;
  }

  if (hours > 0) {
    // hh:mm
    displayNumber(h1,3,color); 
    displayNumber(h2,2,color);
    displayNumber(m1,1,color);
    displayNumber(m2,0,color);  
  } else {
    // mm:ss   
    displayNumber(m1,3,color);
    displayNumber(m2,2,color);
    displayNumber(s1,1,color);
    displayNumber(s2,0,color);  
  }

  displayDots(color);  

  if (hours <= 0 && remMinutes <= 0 && remSeconds <= 0) {
    Serial.println("Countdown timer ended.");
    //endCountdown();
    countdownMilliSeconds = 0;
    endCountDownMillis = 0;
    digitalWrite(COUNTDOWN_OUTPUT, HIGH);
    return;
  }  
}

void endCountdown() {
  allBlank();
  for (int i=0; i<NUM_LEDS; i++) {
    if (i>0)
      LEDs[i-1] = CRGB::Black;
    
    LEDs[i] = CRGB::Red;
    FastLED.show();
    delay(25);
  }  
}

void displayDots(CRGB color) {
  if (dotsOn) {
    LEDs[42] = color;
    LEDs[43] = color;
  } else {
    LEDs[42] = CRGB::Black;
    LEDs[43] = CRGB::Black;
  }

  dotsOn = !dotsOn;  
}

void hideDots() {
  LEDs[42] = CRGB::Black;
  LEDs[43] = CRGB::Black;
}

void updateTemperature() {
  RtcTemperature temp = Rtc.GetTemperature();
  float ftemp = temp.AsFloatDegC();
  float ctemp = ftemp + temperatureCorrection;
  Serial.print("Sensor temp: ");
  Serial.print(ftemp);
  Serial.print(" Corrected: ");
  Serial.println(ctemp);

  if (temperatureSymbol == 13)
    ctemp = (ctemp * 1.8000) + 32;

  byte t1 = int(ctemp) / 10;
  byte t2 = int(ctemp) % 10;
  CRGB color = CRGB(r_val, g_val, b_val);
  displayNumber(t1,3,color);
  displayNumber(t2,2,color);
  displayNumber(11,1,color);
  displayNumber(temperatureSymbol,0,color);
  hideDots();
}

void updateScoreboard() {
  byte sl1 = scoreboardLeft / 10;
  byte sl2 = scoreboardLeft % 10;
  byte sr1 = scoreboardRight / 10;
  byte sr2 = scoreboardRight % 10;

  displayNumber(sl1,3,scoreboardColorLeft);
  displayNumber(sl2,2,scoreboardColorLeft);
  displayNumber(sr1,1,scoreboardColorRight);
  displayNumber(sr2,0,scoreboardColorRight);
  hideDots();
}

void printDateTime(const RtcDateTime& dt)
{
    char datestring[20];

    snprintf_P(datestring, 
            countof(datestring),
            PSTR("%02u/%02u/%04u %02u:%02u:%02u"),
            dt.Month(),
            dt.Day(),
            dt.Year(),
            dt.Hour(),
            dt.Minute(),
            dt.Second() );
    Serial.println(datestring);
}

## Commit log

2020-05-15 Other files
    [3DModel.FCStd, BinaryNumbers.xlsx]
2020-05-16 Added stand and 12/24 hour format
    [3DModel.FCStd, Backlid.stl, Spacer.stl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]
2020-05-16 Cleanup and datetime fix
    [7-Segment-Clock.ino]
2020-05-16 Added STL files
2020-06-06 Added output pin D5 to get active HIGH when countdown timer reaches 0
